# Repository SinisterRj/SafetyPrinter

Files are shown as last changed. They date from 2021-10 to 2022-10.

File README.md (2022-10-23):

# SafetyPrinter
This project aims to improve the safety of 3D FDM Printers by adding an external MCU (an Arduino) which increases your chance of preventing or mitigating a fire at your home.

Safety Printer MCU assembly
_Safety Printer MCU assembly_

The project itself is very simple and designed to be cheap (the minimum needed is an Arduino nano and a few sensors). All you need is some time to assemble everything and test.

This project has a sibling project, the [Octoprint's Safety Printer plugin](https://github.com/SinisterRj/Octoprint_SafetyPrinter) which is optional but it's highly recommended as it helps you monitor your sensors and helps a lot during test phase:

Sidebar1

You can find lots of information on [Wiki](https://github.com/SinisterRj/SafetyPrinter/wiki) and we recommend it's reading.

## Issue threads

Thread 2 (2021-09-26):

Request: List of supported sensors / smoke detectors

ascheucher, 2021-09-26:
Hi SinisterRJ,

just stumbled over your plugin / Arduino firmware. The idea sounds great!

I consider to build rebuild the whole thing in some time, but hove no idea which sensors / smoke detectors are supported.

Would you mind to list them in the Wiki?

Thanks in advance,
Andreas

SinisterRj, 2021-09-26:
Hi Andreas,

Nice sugestion, I'll implement. But you can use any smoke detector with "dry contact" alarm indication (usually they have four wire connection, two for power supply and 2 for the signal). They are the simpler ones. We don't offer support to any wireless sensor or 2 wire sensor that use any digital communication protocol.

ascheucher, 2021-09-27:
Thanks for your response. Had no experience with other than battery operated ones so far.
[Would this one for example be ok?](https://www.alibaba.com/product-detail/4-Wire-Relay-Output-Dry-Contact_60517976368.html)
It states dry contact...

[Is it wired up similar to this?](https://www.instructables.com/Prevent-House-Fires-with-the-Smoke-Detector-Discon/)

I assume your project is in early stage and there is more info (like wiring diagrams) to come?

SinisterRj, 2021-09-27:
Yes, this one is ok! And you don't need this kind of modification. A 4 wire smoke detector is very simple. 2 wires are the power supply, usually + 12 Vdc and Ground. The other 2 wires works like a ordinary switch. If you set it to be "normally open", the switch will de closed (short circuited) in normal condition, and will de open when some smoke hits the detector. Normally close is the oposite. Usually the detector have a jumper to select if you want a "normally open" or "normally close" mode.
All that you need to do about the wiring is to connect the 4 wires of the smoke sensor as drawed here:
[Schematics](https://github.com/SinisterRj/SafetyPrinter/blob/main/Schematics/Schematics.pdf)

ascheucher, 2021-09-28:
Oh, I missed the diagram!

Sounds good. Thanks for your explanation!

I hope I find time to dig into it soon.

SinisterRj, 2021-10-19:
Done!
[https://github.com/SinisterRj/SafetyPrinter/wiki/Supported-sensors](https://github.com/SinisterRj/SafetyPrinter/wiki/Supported-sensors)

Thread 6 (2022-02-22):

Feature Request: Support PSU Shutdown as subplugin

ivebeenlinuxed, 2022-02-22:
Would it be possible to implement a command in this library to query the printerPowered boolean as a new command "r6"?

This would give full functionality to implement the OctoPrint companion plugin as a subplugin of "PSUControl".

Sample source for subplugin requires "turn on", "turn off" and "get state":
https://github.com/kantlivelong/OctoPrint-PSUControl/blob/master/extra/psucontrol_subpluginexample.py

SinisterRj, 2022-02-23:
Hello!
I'm not sure if I got what you want. If do you mean to shutdown the printer when some sensor triggers throught another plugin, it is technically possible, but filosophically  speaking wrong. The idea behind this project is to have an automonous and independent system to shutdown your printer when everything else fails. So, the Safety Printer mcu (the arduino) takes this decision alone, the octoprint plugin is not needed for the safety action take its place. When you use another plugin to do that, many other parts must work flawlessly to the shutdown happens (i.e. rapsberry pi, octoprint, etc).

ivebeenlinuxed, 2022-02-24:
Hi! Thanks for the reply!

I completely agree that the safety printer plugin should autonomously, and without interferance, be able to shut down the printer. That is without question. I also agree that a safety interlock with another plugin is also a flawed implementation.

My point regards command <c6>. This allow the unit to "turn off/on" without the safety interlock state changing - from my brief understanding of the code. This is not a safety feature, but gives the user the choice of remotely turning off the unit when it is idle. I would assume the Octoprint option of "shutdown after print" uses this to cut power without tripping the interlock. Likewise, if the unit is tripped it will not start up again without a reset.

The "shutdown after print" is an overlapping feature with another plugin PSUControl. This power related (not safety related) feature would be better integrated into this plugin to improve support for "scheduled on/scheduled off/shutdown when cool/shutdown when idle" type features that SafetyPrinter implements to a lesser extent. This would prevent users having to attach a second device for powering the printer down at times of low demand.

My request would be simply that a new command would return 0 or 1, showing if the unit was powered off by <c6>. This would allow the PSUControl plugin to determine the current state of the relay and decide to power on and off the unit in innovative ways - supposing the interlock was not triggered. The PSU control could then issue a <c6> command to change the PSU state, should it want to.

This is not a safety feature, but offloading the user options of shutdowns and power ups, so long as the printer is safe, to another plugin. It does not give the plugin access to <reset>, which is completely different. What do you think?

SinisterRj, 2022-03-11:
Implemented via <r7> command. It returns "t" of "f" to printer's power on status.

Closed 2022-07-18.

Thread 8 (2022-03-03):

Bug: Octoprint_safetyprinter requires reset which cuts power on connect

ivebeenlinuxed, 2022-03-03:
At the moment, the octoprint plugin looks for the boot message when starting. This means that if the serial port to the safetyprinter disconnects, and then is made to reconnect the power is pulled to the printer during boot.

What would I like:
r7 command "ping" with a response "pong" to show that the Arduino is ready without having to reboot

ivebeenlinuxed, 2022-03-03:
I have a pull request for this, but not sure opening a pull request for r7 command, when r6 is still pending is wise

SinisterRj, 2022-03-03:
Hello my friend, this is an Arduino behavior not a safety printer's bug. Everytime you connect to an arduino (Uno ou nano) it resets. You can modify you arduino board to remove this feature, but you compromise other stuff (like need to reset upon a flash). Arduino Leonardo don't reset upon connection, but needs a manual reset to flash. This is something that I am working on.

ivebeenlinuxed, 2022-03-03:
Hi!

Indeed this is an Arduino feature, which I have solved with the 10uF capacitor between GND and RST. The issue is now that the printer needs to see another message apart from the boot message to know the connection is alive. I have replaced the connect test function to look for "pong" in response to "ping". This way, the board does not need to reboot to get the expected response message.

I shall send you the related pull request for the Octoprint plugin tomorrow.

SinisterRj, 2022-03-04:
I already fixed this at home but not pushed to GitHub yet, because I'm not sure if it is the best approach. I'm using [Firmware Updater Plugin](https://plugins.octoprint.org/plugins/firmwareupdater/) and  using the capacitor (or Arduino Leonardo) requires to push reset button to flash the firmware. Considering that the Safety Printer board will be usually located somewhere not very accessible and far from the computer, it will be impractical to use the plugin to update the safety printer`s firmware.

SinisterRj, 2022-03-04:
Maybe, one approach is to use the raspberry pi to force arduino`s reset or, create some command to reset the Arduino.

SinisterRj, 2022-03-11:
Hello. I updated the github with my latest code (devel branch). It already supports Arduino Leonardo (or Uno/nano with the capacitor to avoid reset), but you must reflash your arduino with the devel firmware too.

ivebeenlinuxed, 2022-03-28:
Hi @SinisterRj - Sorry for the delay. I've been away and didn't have access to my printer.

The other problem that needs fixing is that the Octoprint_SafetyPrinter needs to not wait for the boot text, but if already booted, should wait for a "ping".

I've put this here:
https://github.com/ivebeenlinuxed/Octoprint_SafetyPrinter/commit/507307af4ccb8985f92de0c35f0469ff2cc52220

The corresponding "ping" command is in my commit here:
https://github.com/ivebeenlinuxed/SafetyPrinter/commit/856076953db4fa97ddb625f6897dfc941f4eed87

Obviously there are some backwards compatibility issues here, as older versions of the SafetyPrinter firmware does not have the new "ping" command.

I guess this will need some tweaking, and maybe I need to get this all committed on dev branches....

Shall I do two pull requests for these - one to each repo?

SinisterRj, 2022-07-19:
Hello @ivebeenlinuxed . I've been away from the project for some time, and now I could take a look on your suggestions. The problem avoiding the reset with a capacitor creates another problem: the need of pressing the reset button to flash the arduino. I studied the problem for some time, because I did want to solve it by software, but as far I went, the bootloader just enters in programming mode when the RST pin is lowered. So I couldn't find another way than use a digital port to autoreset the arduino.
After this been said, I was already understod that the handshake should be different and already changed it locally, So I will use my code.
And thanks for the "threading" commit.
I hope you enjoy the new devel release, but keep in mind that you will need to reflash your arduino.

Closed 2022-07-19.

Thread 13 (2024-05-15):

WatchDog library only supports AVR processors

ctbjdm, 2024-05-15:
There aren't any clear specs for the Arduino beyond "Arduino Uno or Nano".  Trying to compile it in the Arduino IDE, for an Arduino UNO R4 Minima (seemed like a reasonable purchase for this) doesn't work.  I get the error below.

Seems you need to use an AVR core based Arduino to use this as-is.  Switching to an older AVR Arduino (ordered) to see if it resolves it.

------------------------------------------------------------------------------------------------------------
In file included from C:\Users\me\Documents\Arduino\SafetyPrinter\SafetyPrinter.ino:1:0:
C:\Users\me\Documents\Arduino\libraries\WatchDog/WatchDog.h:78:2: error: #error The WatchDog library only supports AVR processors
 #error The WatchDog library only supports AVR processors
  ^~~~~
C:\Users\me\Documents\Arduino\SafetyPrinter\SafetyPrinter.ino:112:10: fatal error: avr/wdt.h: No such file or directory
 #include <avr/wdt.h>                        // Watchdog
          ^~~~~~~~~~~
compilation terminated.
exit status 1

Compilation error: avr/wdt.h: No such file or directory
------------------------------------------------------------------------------------------------------------

Note - this looks excellent - thank you SinisterRj

SinisterRj, 2024-07-26:
BOM updated with the right MCU information. Thanks

Closed 2024-07-26.

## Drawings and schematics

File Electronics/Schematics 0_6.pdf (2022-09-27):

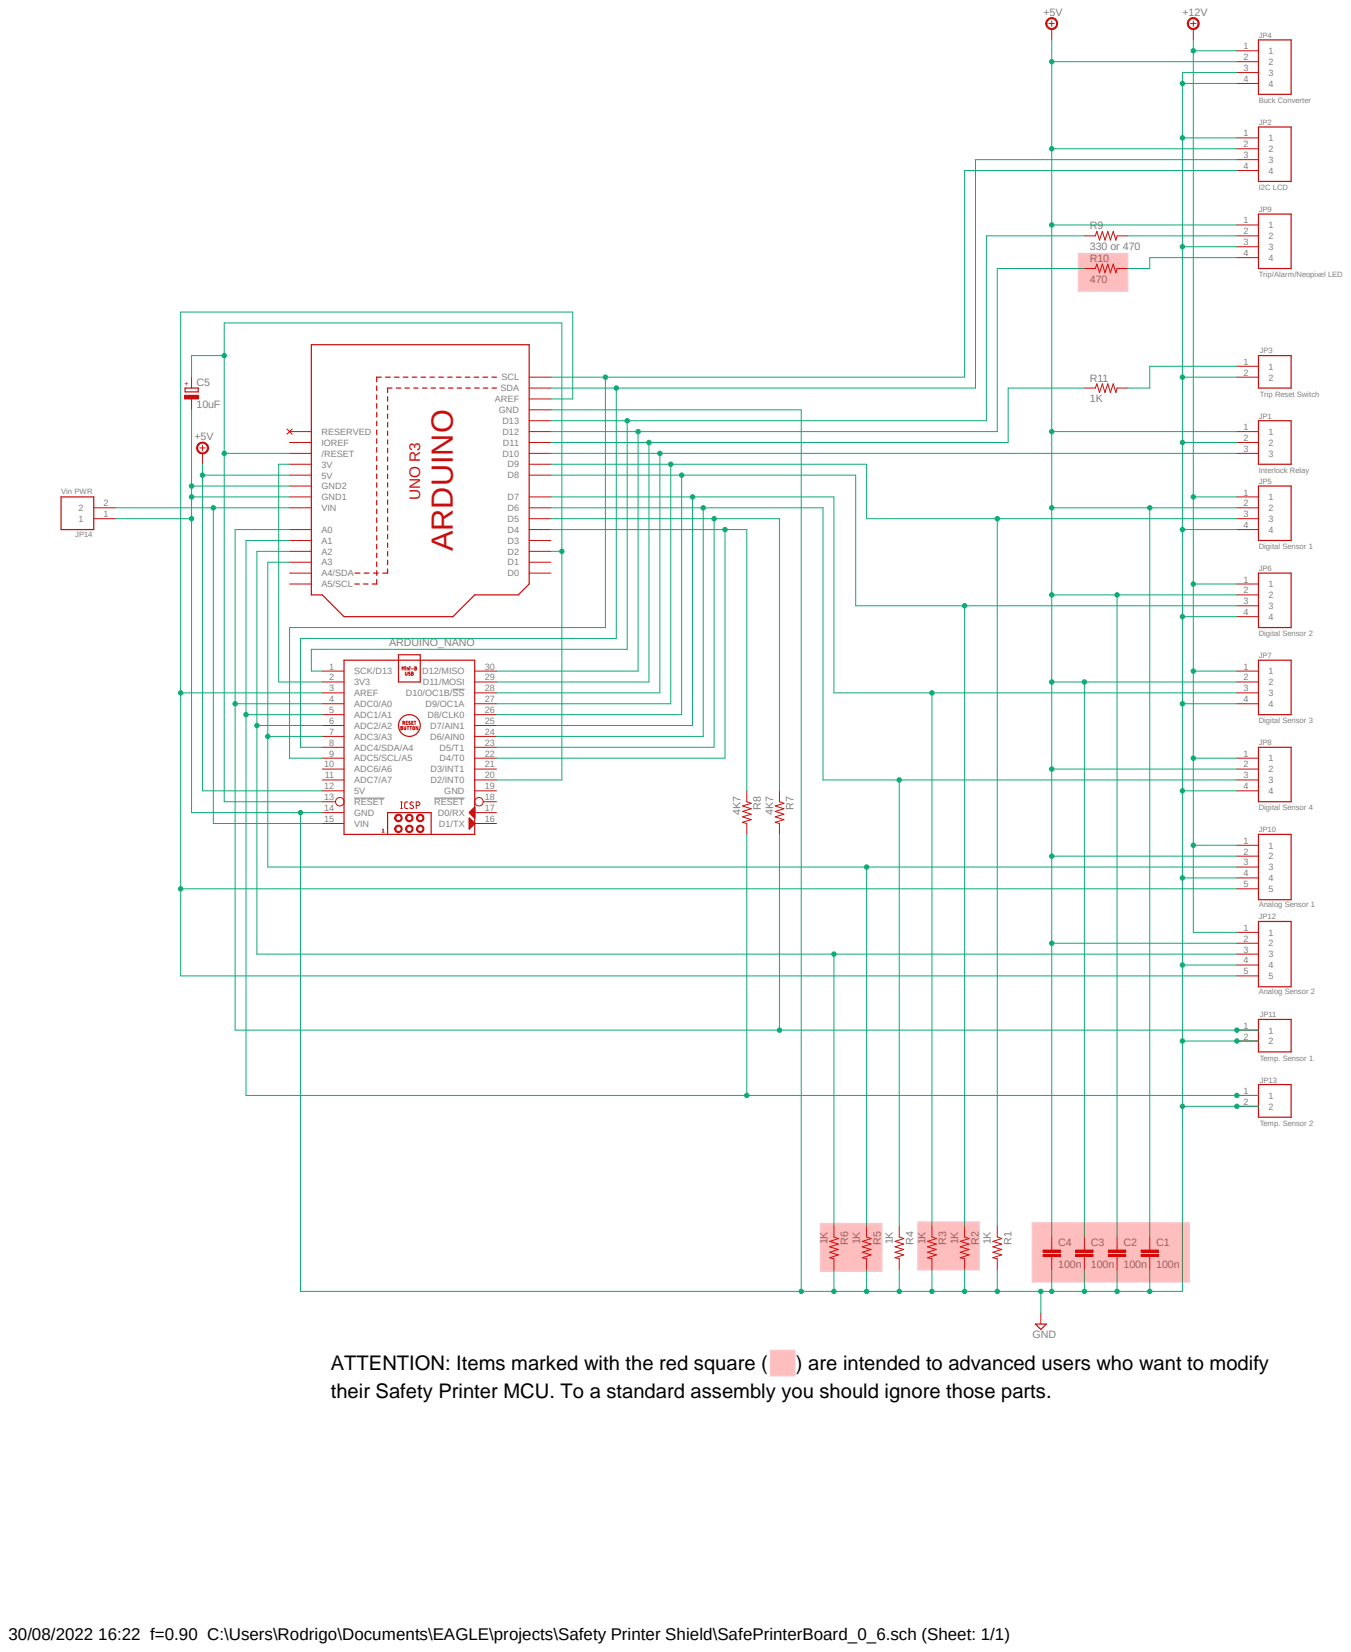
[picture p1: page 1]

JP9 Trip/Alarm/Neopixel LED ARDUINO UNO R³

30/08/2022 16:22 f=0.90 C:\Users\Rodrigo\Documents\EAGLE\projects\Safety Printer Shield\SafePrinterBoard_0_6.sch (Sheet: 1/1)

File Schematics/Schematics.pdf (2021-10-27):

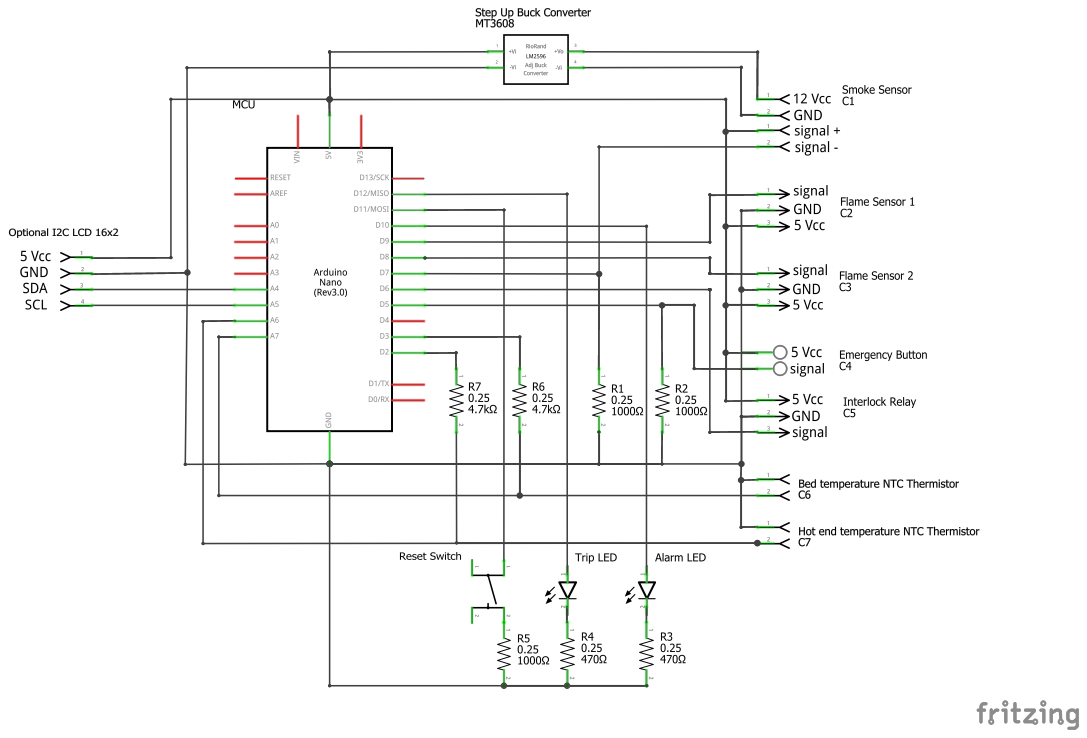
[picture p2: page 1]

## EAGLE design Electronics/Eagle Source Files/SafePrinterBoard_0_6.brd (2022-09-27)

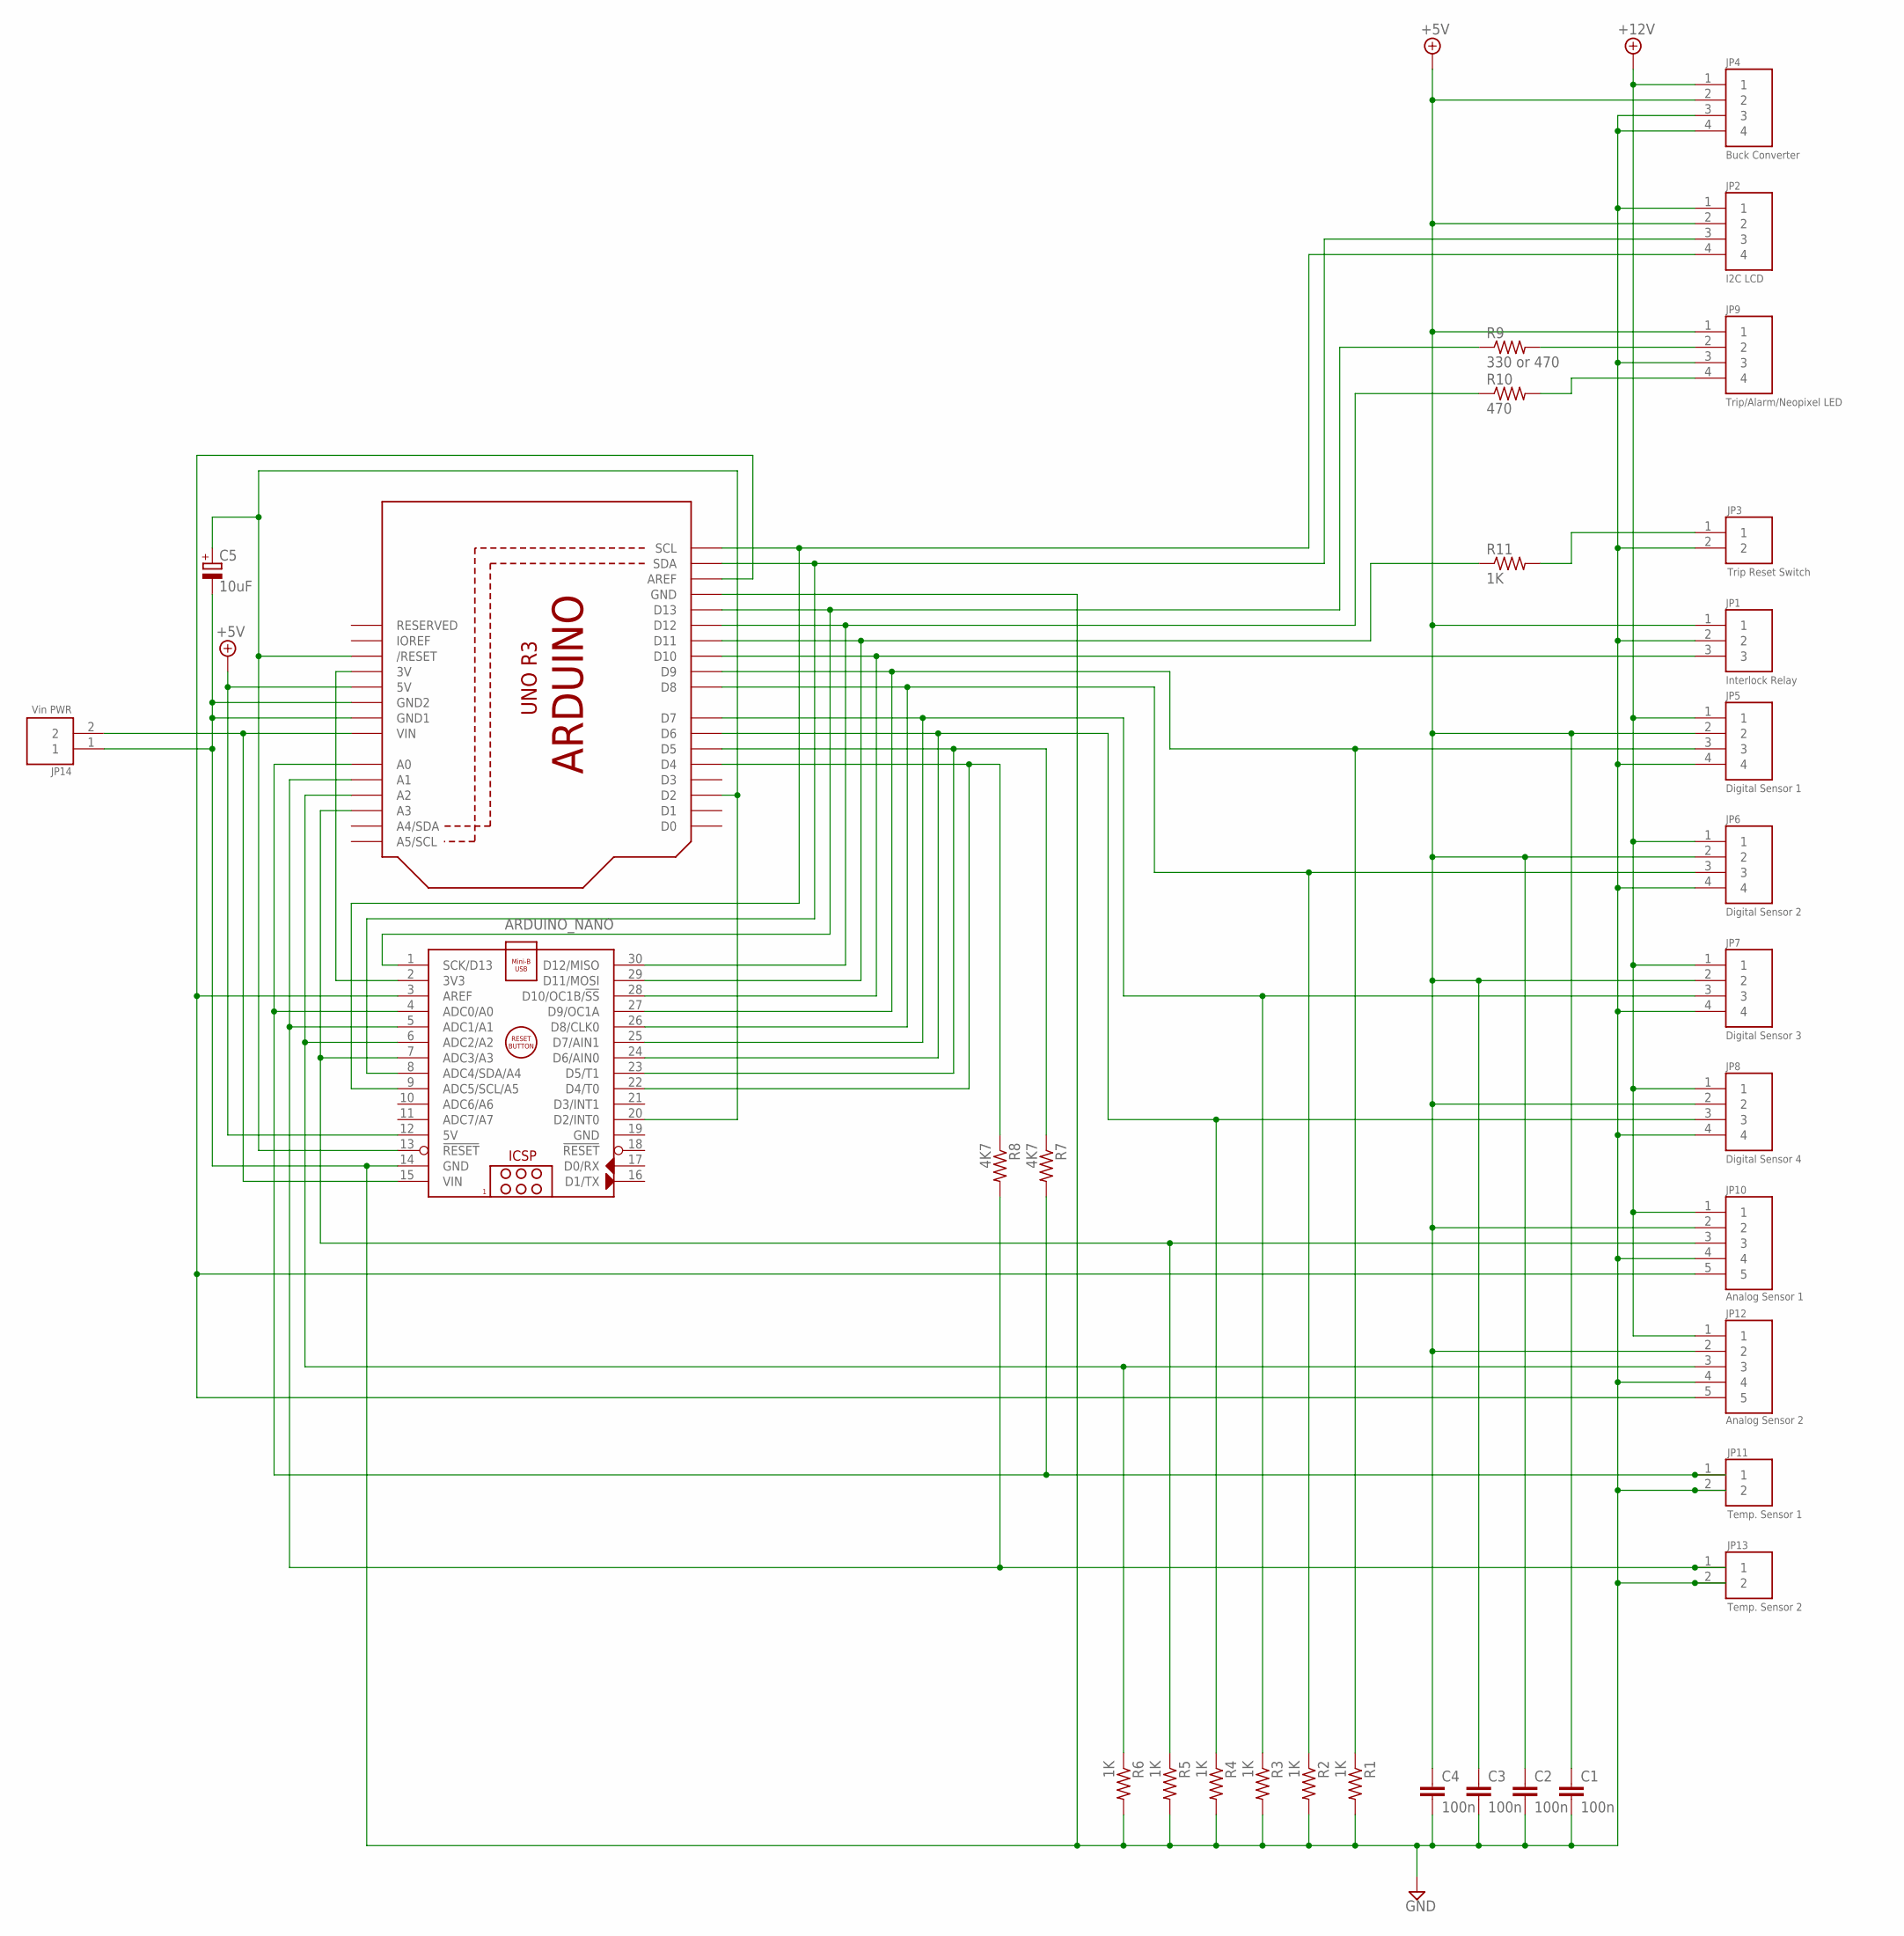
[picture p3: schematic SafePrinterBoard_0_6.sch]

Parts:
ARDUINO_NANO: ARDUINO_NANO
C1, C2, C3, C4: 100n; C025-025X050
C5: 10uF; E2-5
JP1: Interlock Relay; B3B-PH-K-S
JP2: I2C LCD; B4B-PH-K-S
JP3: Trip Reset Switch; B2B-PH-K-S
JP4: Buck Converter; B4B-PH-K-S
JP5: Digital Sensor 1; B4B-PH-K-S
JP6: Digital Sensor 2; B4B-PH-K-S
JP7: Digital Sensor 3; B4B-PH-K-S
JP8: Digital Sensor 4; B4B-PH-K-S
JP9: Trip/Alarm/Neopixel LED; B4B-PH-K-S
JP10: Analog Sensor 1; B5B-PH-K-S
JP11: Temp. Sensor 1; B2B-PH-K-S
JP12: Analog Sensor 2; B5B-PH-K-S
JP13: Temp. Sensor 2; B2B-PH-K-S
JP14: Vin PWR; B2B-PH-K-S
R1, R2, R3, R4, R5, R6, R11: 1K; 0805-THM
R7, R8: 4K7; 0805-THM
R9: 330 or 470; 0805-THM
R10: 470; 0805-THM
U1: ARDUINOR3-BPLACE

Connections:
+5V: ARDUINO_NANO.12 (5V), C1.1, C2.1, C3.1, C4.1, JP1.1, JP2.2, JP4.2, JP5.2, JP6.2, JP7.2, JP8.2, JP9.1, JP10.2, JP12.2, U1.5V
+12V: JP4.1, JP5.1, JP6.1, JP7.1, JP8.1, JP10.1, JP12.1
GND4: ARDUINO_NANO.14 (GND), ARDUINO_NANO.19 (GND), C1.2, C2.2, C3.2, C4.2, C5.-, JP1.2, JP2.1, JP3.2, JP4.3, JP4.4, JP5.4, JP6.4, JP7.4, JP8.4, JP9.3, JP10.4, JP11.2, JP12.4, JP13.2, JP14.1, R1.2, R2.2, R3.2, R4.2, R5.2, R6.2, U1.GND, U1.GND1, U1.GND2
unnamed: ARDUINO_NANO.28 (D10/OC1B/!SS), JP1.3, U1.D10
unnamed: ARDUINO_NANO.24 (D6/AIN0), JP8.3, R4.1, U1.D6
unnamed: JP9.2, R9.2
unnamed: ARDUINO_NANO.26 (D8/CLK0), JP6.3, R2.1, U1.D8
unnamed: ARDUINO_NANO.25 (D7/AIN1), JP7.3, R3.1, U1.D7
unnamed: ARDUINO_NANO.27 (D9/OC1A), JP5.3, R1.1, U1.D9
unnamed: ARDUINO_NANO.1 (SCK/D13), R9.1, U1.D13
unnamed: ARDUINO_NANO.30 (D12/MISO), R10.1, U1.D12
unnamed: ARDUINO_NANO.29 (D11/MOSI), R11.1, U1.D11
unnamed: ARDUINO_NANO.9 (ADC5/SCL/A5), JP2.4, U1.SCL
unnamed: ARDUINO_NANO.8 (ADC4/SDA/A4), JP2.3, U1.SDA
unnamed: ARDUINO_NANO.23 (D5/T1), R7.1, U1.D5
unnamed: JP9.4, R10.2
unnamed: ARDUINO_NANO.22 (D4/T0), R8.1, U1.D4
unnamed: ARDUINO_NANO.7 (ADC3/A3), JP10.3, R5.1, U1.A3
unnamed: ARDUINO_NANO.6 (ADC2/A2), JP12.3, R6.1, U1.A2
unnamed: ARDUINO_NANO.13 (!RESET), ARDUINO_NANO.20 (D2/INT0), C5.+, U1.D2, U1.RESET (/RESET)
unnamed: ARDUINO_NANO.15 (VIN), JP14.2, U1.VIN
unnamed: ARDUINO_NANO.4 (ADC0/A0), JP11.1, R7.2, U1.A0
unnamed: ARDUINO_NANO.5 (ADC1/A1), JP13.1, R8.2, U1.A1
unnamed: ARDUINO_NANO.3 (AREF), JP10.5, JP12.5, U1.AREF
unnamed: ARDUINO_NANO.2 (3V3), U1.3V
unnamed: JP3.1, R11.2

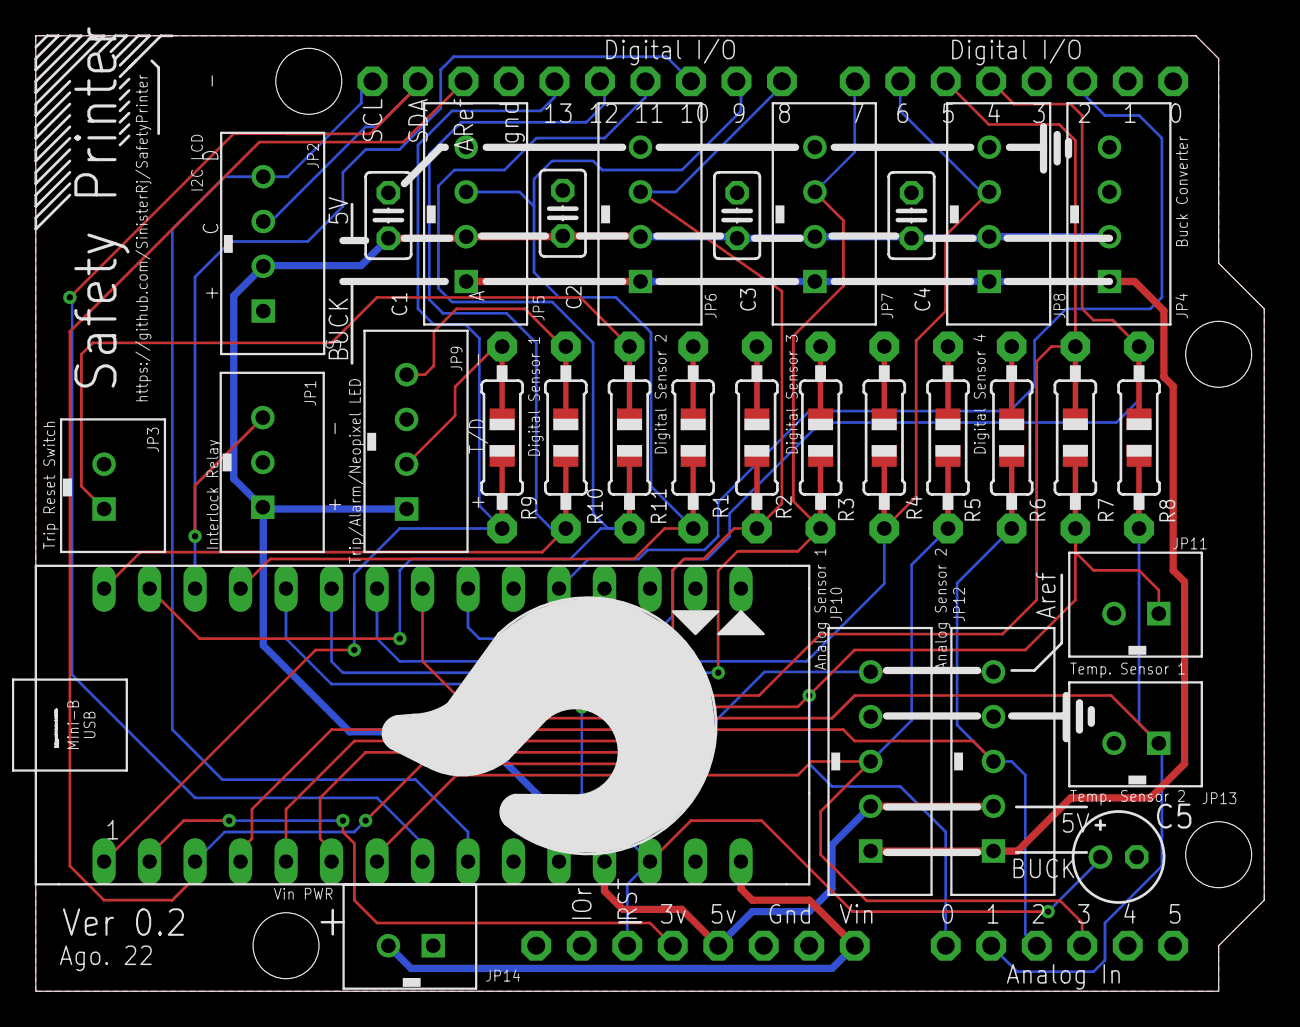
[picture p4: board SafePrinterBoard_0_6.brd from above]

Board: 2 copper layers, 68.6 x 53.3 mm, 32 parts (0 on the bottom side), 26 nets.

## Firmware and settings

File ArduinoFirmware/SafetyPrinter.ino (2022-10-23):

/**
 * Safety Printer Firmware
 * Copyright (c) 2021~22 Rodrigo C. C. Silva [https://github.com/SinisterRj/SafetyPrinter]
 *
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
 * WARNING: DON'T CHANGE ANYTHING IN THIS FILE! ALL CONFIGURATIONS SHOULD BE DONE IN "Configurations.h".
 *
 * Version 0.2.7
 * 22/10/22
 * Changes:
 * 1) Monitors RESET button to a continuous operation (shortcircuited) and disables it to avoid auto reset after a trip.
 * 2) Fix a bug that crashes the serial communication if the sensor Label was grater then 16 chars.
 * 
 * Version 0.2.6
 * 27/09/22
 * Changes:
 * 1) New default pin out to match with the official Safety Printer Arduino Shield;
 * 2) Include <R6> command to repeat intro msg;
 * 3) Remove "booting..." string from the setup;
 * 4) Auto detects different Arduino boards;
 * 5) Include command <r7> to report Printer's power status (user request) - Integration with PSU Control;
 * 6) Include command <c9> to reset the Safety Printer MCU. This command allows firmware update.
 * 7) Command <R4> returns board Type;
 * 8) Include ARDUINO_RESET_PIN;
 * 9) Include neopixels as status indicator;
 * 10) Fix a bug that makes wrong temperature readings if your declared sensor that don't match with the sensor's count.
 * 
 * Version 0.2.5
 * 10/21/2021
 * Changes:
 * 1) Include CRC check on <r1>,<r2> and <r4> responses;
 * 2) Organize some thermisotr tables and Configuration.h file;
 * 3) Check for some errors on sensor configuration and disable it.
 * 4) Include commands alias;
 * 5) Include free memory, voltage, temperature and cycle time monitoring;
 * 6) Include I2C 16x2 LCD support
 * 7) Creates "lowSP" and "highSP" sensor values (now user can choose different sensors);
 * 8) <R2> now sends "forceEnable", "lowSP" and "highSP" values;
 * 9) Include a timer to avoid sucessive trips/resets or turns on/off on printer and damage it.
 * 
 * Version 0.2.4
 * 07/30/2021
 * Changes:
 * 1) Include Marlin Thermistor files for better thermistor configuration;
 * 2) Configuration.h created.
 *
 * Version 0.2.3
 * Changes:
 * 1) Fix a bug when reading EEPROM data.
 * 2) Split project into multiple files.
 * 3) Checks EEPROM for CRC.
 * 4) Update <c4> command to send EEPROM and Serial Protocol versions
 * 
 * Version 0.2.2
 * Changes:
 * 1) Defined limits for set point definition.
 * 2) Now EEPROM read uses the addr 0 as a version flag. If it is different from EEPROMVERSION (because new release changed EEPROM structure), the firmware will overwrite it.
 * 3) Include command C5 to turn off the printer.
 * 4) Commands and arguments are now case insensitive.
 * 5) Included command <c7> to change sensor timers.
 * 6) included command <c1> to return sensors configuration (enabled, alarm set point and timer) back to original values.
 * 7) Fix a bug that interpretates no argument as argument 0 in some commands.
 * 
 * Version: 0.2.1
 * 05/26/2021
 * Changes: 
 * 1) Include analog type of sensor to allow Hotend temperature measurement.
 * 2) included command <c5> to save on EEPROM sensors Enabled status and alarm set points
 * 3) 2 new serial commands: Remote shutdown and enable/disable sensors 
 * 4) Now it indicates Alarm even if the sensor is disabled (but not starts de trip)
 * 5) Included command <r4> to return firmware version and release date
 * 
 */
 
//#define DEBUG   
#ifdef DEBUG                                // Just for debug porpouses
  #define DEBUG_DELAY           1000        // Debug timer renew
#endif

#define LOOP_TIME_SAMPLES       25          // Number of samples to calculate main loop time.

#define DIGIGTAL_SENSOR         0           // Internal use, don't change
#define NTC_SENSOR              1           // Internal use, don't change

// Board Codes
#define UNO                     1
#define NANO                    2
#define LEONARDO                3

//Number of chars in sensors label
#define NUMCHARLABEL            16

#include <Arduino.h>                        // Needed to compile with Platformio
#include <avr/wdt.h>                        // Watchdog
#include <EEPROM.h>                         // EEPROM access
#include "Configuration.h"

#ifdef HAS_LCD
  #include <Wire.h>
  #include <LiquidCrystal_I2C.h>
#endif

// *************************** Don't change after this line **********************************
// *******************************************************************************************

#define VERSION                 "0.2.7"
#define RELEASEDATE             "Oct 13 2022"
#define EEPROMVERSION           3            // Incremental BYTE. Firmware overwrites the EEPROM with standard values if the number readed from EEPROM is different. change everytime that EEPROM structure is changed.
#define COMMPROTOCOL            6            // Incremental BYTE. Octoprint plugin communication protocol version. 

char forb_chars[] = {',','#','$',':','<','>'};   // forbiden characters for sensor names
//int availableThermistors[] = {1,2,3,4,5,6,7,8,9,10,11,12,13,15,17,18,20,21,22,23,30,51,52,55,60,61,66,67,70,71,75,99,331,332,998,999};
 
// another .ino functions:
int highest_temp(byte sensorNumber);
int lowest_temp(byte sensorNumber);

typedef struct
{
  int8_t index;
  char label[NUMCHARLABEL+1];
  int8_t pin;
  int8_t auxPin;
  uint8_t type;
  unsigned long timer;
  int alarmSP;
  bool enabled;
  bool active;
  int actualValue;
  bool forceDisable;
  bool trigger;
  int lowSP;
  int highSP;
  int16_t tTI; //temp table index
} tSensor;

typedef struct
{
  unsigned long timer;
  int alarmSP;
  bool enabled;
} tDefault;

/* ****************************************************************************
 Declare all sensors using the above template
 "label",pin number,delay,enabled,alarmStatus,forceDisable,trigger,spare3,spare4

 Label: the name of the sensor, that will help you to intentify it;
 Pin number: the pin wher it is connected;
 Delay: The timer delay to start the interlock from this sensor. If two or more sensors are active, the delay is bypassed; 
 Normal Condition: The variable status during normal operation. For analog variables, use the greater normal value (i.e. 279 if you want to trip with 280)
 enabled, alarmStatus: Internal use.

*/

tSensor sensors [] =
{   
#ifdef SENSOR_1_LABEL
   0,"",SENSOR_1_PIN,
   #ifdef SENSOR_1_AUX_PIN 
      SENSOR_1_AUX_PIN, 
   #else 
      -1, 
   #endif
   SENSOR_1_TYPE,SENSOR_1_TIMER,SENSOR_1_ALARM_SP,true,false,0,false,false,
   #ifdef SENSOR_1_TEMP_TYPE 
      0,0,SENSOR_1_TEMP_TYPE, 
   #else 
      0,1,0,
   #endif
#endif 
#ifdef SENSOR_2_LABEL
   1,"",SENSOR_2_PIN,
   #ifdef SENSOR_2_AUX_PIN 
      SENSOR_2_AUX_PIN, 
   #else 
      -1, 
   #endif
   SENSOR_2_TYPE,SENSOR_2_TIMER,SENSOR_2_ALARM_SP,true,false,0,false,false,
   #ifdef SENSOR_2_TEMP_TYPE 
      0,0,SENSOR_2_TEMP_TYPE, 
   #else 
      0,1,0,
   #endif
#endif 
#ifdef SENSOR_3_LABEL
   2,"",SENSOR_3_PIN,
   #ifdef SENSOR_3_AUX_PIN 
      SENSOR_3_AUX_PIN, 
   #else 
      -1, 
   #endif
   SENSOR_3_TYPE,SENSOR_3_TIMER,SENSOR_3_ALARM_SP,true,false,0,false,false,
   #ifdef SENSOR_3_TEMP_TYPE 
      0,0,SENSOR_3_TEMP_TYPE, 
   #else 
      0,1,0, 
   #endif
#endif 
#ifdef SENSOR_4_LABEL
   3,"",SENSOR_4_PIN,
   #ifdef SENSOR_4_AUX_PIN 
      SENSOR_4_AUX_PIN, 
   #else 
      -1, 
   #endif
   SENSOR_4_TYPE,SENSOR_4_TIMER,SENSOR_4_ALARM_SP,true,false,0,false,false,
   #ifdef SENSOR_4_TEMP_TYPE 
      0,0,SENSOR_4_TEMP_TYPE, 
   #else 
      0,1,0, 
   #endif
#endif 
#ifdef SENSOR_5_LABEL
   4,"",SENSOR_5_PIN,
   #ifdef SENSOR_5_AUX_PIN 
      SENSOR_5_AUX_PIN, 
   #else 
      -1, 
   #endif
   SENSOR_5_TYPE,SENSOR_5_TIMER,SENSOR_5_ALARM_SP,true,false,0,false,false,
   #ifdef SENSOR_5_TEMP_TYPE 
      0,0,SENSOR_5_TEMP_TYPE, 
   #else 
      0,1,0, 
   #endif
#endif 
#ifdef SENSOR_6_LABEL
   5,"",SENSOR_6_PIN,
   #ifdef SENSOR_6_AUX_PIN 
      SENSOR_6_AUX_PIN, 
   #else 
      -1, 
   #endif
   SENSOR_6_TYPE,SENSOR_6_TIMER,SENSOR_6_ALARM_SP,true,false,0,false,false,
   #ifdef SENSOR_6_TEMP_TYPE 
      0,0,SENSOR_6_TEMP_TYPE, 
   #else 
      0,0,0, 
   #endif
#endif 
#ifdef SENSOR_7_LABEL
   6,"",SENSOR_7_PIN,
   #ifdef SENSOR_7_AUX_PIN 
      SENSOR_7_AUX_PIN, 
   #else 
      -1, 
   #endif
   SENSOR_7_TYPE,SENSOR_7_TIMER,SENSOR_7_ALARM_SP,true,false,0,false,false,
   #ifdef SENSOR_7_TEMP_TYPE 
      0,0,SENSOR_7_TEMP_TYPE, 
   #else 
      0,1,0, 
   #endif
#endif 
#ifdef SENSOR_8_LABEL
   7,"",SENSOR_8_PIN,
   #ifdef SENSOR_8_AUX_PIN 
      SENSOR_8_AUX_PIN, 
   #else 
      -1, 
   #endif
   SENSOR_8_TYPE,SENSOR_8_TIMER,SENSOR_8_ALARM_SP,true,false,0,false,false,
   #ifdef SENSOR_8_TEMP_TYPE 
      0,0,SENSOR_8_TEMP_TYPE, 
   #else 
      0,1,0, 
   #endif
#endif 
};

tDefault defaultSensors[(sizeof(sensors) / sizeof(sensors[0]))];

typedef struct
{
  unsigned long startMs = 0;
  bool started = false;
} tTimer;

/*
//Defines the SP limits for each of the sensor types. 
int SPLimits[2][2] = {
  { 0, 1 },   // type 0 = Digital
  { 0, 300 }  // type 1 = NTC temperature
};*/
bool interlockStatus = false;
bool interlockStatusChanged = false;
bool anyAlarm = false;
uint8_t activeAlarmCount = 0;
uint8_t numOfSensors = 0;
tTimer interlockTimer, resetTimer, minimumInterlockTimer, inhibitResetTimer;
bool printerPowered = true;
unsigned int lTLastRecord = 0;
long lTStartTime;
long lTSum = 0;
long lTMax = 0;
long lTNow, lTLastMax, lTLastSum;
bool memWrng, tempWrng, voltWrng, execWrng  = false;
byte triggerIndex = 255;
bool resetBtnPressed = false;
bool inhibitReset = false;



#ifdef DEBUG
   tTimer debugTimer;
#endif

#ifdef HAS_LCD
  tTimer LCDTimer;
  bool tripLCD = false;
#endif

#ifdef HAS_SERIAL_COMM
  #define SERIAL Serial
#endif

void setup() {

   //Enabling watchdog timer 4s  
   wdt_enable(WDTO_4S);

   pinMode(ARDUINO_RESET_PIN, OUTPUT);
   digitalWrite(ARDUINO_RESET_PIN, HIGH);
   
   #ifdef HAS_SERIAL_COMM
      SERIAL.begin(BAUD_RATE);
   #endif

   #ifdef HAS_LCD
      lcd_Init();
   #endif
   
   #ifdef HAS_NEOPIXEL ||  ALARM_LED_PIN || TRIP_LED_PIN  
      led_Init();
   #endif
  
   #ifdef RESET_BUTTON_PIN
      pinMode(RESET_BUTTON_PIN, INPUT_PULLUP);
   #endif

   pinMode(INTERLOCK_RELAY_PIN, OUTPUT);
   digitalWrite(INTERLOCK_RELAY_PIN, INTERLOCK_POLARITY);
   startTimer(&minimumInterlockTimer.startMs,&minimumInterlockTimer.started);

   numOfSensors = (sizeof(sensors) / sizeof(sensors[0]));
  
   // check sensor configuration
   validateSensorsInfo();
   
   //Set sensor input pins
   for (int i =0; i < numOfSensors; i++) { 
      if (sensors[i].enabled && !sensors[i].forceDisable) 
      {
         pinMode(sensors[i].pin, INPUT);
         if (sensors[i].auxPin != -1) {
            pinMode(sensors[i].auxPin, OUTPUT);  // Configure power pin. This pin will be used to power the thermistor
         }
      }          
   }

   for (int i =0; i < numOfSensors; i++) { 
      defaultSensors[i].timer = sensors[i].timer;
      defaultSensors[i].alarmSP = sensors[i].alarmSP;
      if (!sensors[i].forceDisable) {
         defaultSensors[i].enabled = sensors[i].enabled;
      } else {
         defaultSensors[i].enabled = false;
      }
   }

   readEEPROMData(); 

   #ifdef DEBUG
      startTimer(&debugTimer.startMs,&debugTimer.started);
   #endif

   #ifdef HAS_LCD
      startTimer(&LCDTimer.startMs,&LCDTimer.started);
   #endif
}

void loop() {

   // Save the loop start time
   lTStartTime = micros();
 
   //Verify sensors
   checkSensors();

   //Verify reset button
   #ifdef RESET_BUTTON_PIN
      checkResetButton();
   #endif

   //Update LEDs
   updateLEDs();   
  
   //Manage Serial communications
   #ifdef HAS_SERIAL_COMM
      // Receive commands from PC
      recvCommandWithStartEndMarkers(); 
   #endif

   //update LCD information 
   #ifdef HAS_LCD
      updateLCD(resetBtnPressed);
   #endif   

   //Debug Info
   #ifdef DEBUG
      if (checkTimer(&debugTimer.startMs,DEBUG_DELAY,&debugTimer.started)) { 
         SERIAL.println();
         SERIAL.print (F("Free memory [bytes]= "));  // 2048 bytes from datasheet
         SERIAL.println (freeMemory());
         SERIAL.print (F("Temperature [C]= "));
         SERIAL.println (readTemp(), 2);
         SERIAL.print (F("Voltage [V]= "));
         SERIAL.println (readVcc(), 2);  // 2.7V to 5.5V from datasheet
         SERIAL.print (F("Execution time max [us] = "));
         SERIAL.println (lTLastMax,DEC); 
         SERIAL.print (F("Execution time average [us] = "));
         SERIAL.println (lTLastSum/LOOP_TIME_SAMPLES, DEC); 
      } else {
         startTimer(&debugTimer.startMs,&debugTimer.started);
      } 
   #endif

   // check board health:
   if (freeMemory() < 205) {  // 10% of total SRAM
      memWrng = true;
   }
   if ((readTemp() > 110) || (readTemp() < -25)) {  // -40 to +125 +-15
      tempWrng = true;
   }
   if ((readVcc() < 2.7) || (readVcc() > 5.5)) { // 2.7 to 5.5 Vcd 
       voltWrng = true;
   }

   // Measures the execution time
   lTLastRecord++;   
   lTNow = micros() - lTStartTime;   
   lTSum += lTNow;
   
   if (lTNow > lTMax) {
      lTMax = lTNow;    
   }
   
   if (lTLastRecord >= LOOP_TIME_SAMPLES) {
      lTLastSum = lTSum;
      lTSum = 0;
      lTLastMax = lTMax;
      lTMax = 0;      
      lTLastRecord = 0;
      if (lTLastMax > 500000) {   // 500 ms
         execWrng = true;
      }
   } 
   
   //Reset watchdog timer
   wdt_reset();
}

void validateSensorsInfo() {   
   // Check sensor configurations that cannot be done by pre-processor
   byte usedPins[21];
   byte arrayPos = 0;
   #ifdef INTERLOCK_RELAY_PIN
      usedPins[arrayPos] = INTERLOCK_RELAY_PIN;
      arrayPos++;
   #endif

   #ifdef RESET_BUTTON_PIN
      usedPins[arrayPos] = RESET_BUTTON_PIN;
      arrayPos++;
   #endif
    
   #ifdef ALARM_LED_PIN
      usedPins[arrayPos] = ALARM_LED_PIN;
      arrayPos++;
   #endif
    
   #ifdef TRIP_LED_PIN
      usedPins[arrayPos] = TRIP_LED_PIN;
      arrayPos++;
   #endif
    
   #ifdef LCD_SDA_PIN
      usedPins[arrayPos] = LCD_SDA_PIN;
      arrayPos++;
   #endif
    
   #ifdef LCD_SCL_PIN
      usedPins[arrayPos] = LCD_SCL_PIN;
      arrayPos++;
   #endif

   // Crops the sensor label if it is larger than NUMCHARLABEL
   #ifdef SENSOR_1_LABEL
   strncpy(sensors[0].label, SENSOR_1_LABEL, NUMCHARLABEL);
   #endif
   #ifdef SENSOR_2_LABEL
   strncpy(sensors[1].label, SENSOR_2_LABEL, NUMCHARLABEL);
   #endif
   #ifdef SENSOR_3_LABEL
   strncpy(sensors[2].label, SENSOR_3_LABEL, NUMCHARLABEL);
   #endif
   #ifdef SENSOR_4_LABEL
   strncpy(sensors[3].label, SENSOR_4_LABEL, NUMCHARLABEL);
   #endif
   #ifdef SENSOR_5_LABEL
   strncpy(sensors[4].label, SENSOR_5_LABEL, NUMCHARLABEL);
   #endif
   #ifdef SENSOR_6_LABEL
   strncpy(sensors[5].label, SENSOR_6_LABEL, NUMCHARLABEL);
   #endif
   #ifdef SENSOR_7_LABEL
   strncpy(sensors[6].label, SENSOR_7_LABEL, NUMCHARLABEL);
   #endif
   #ifdef SENSOR_8_LABEL
   strncpy(sensors[7].label, SENSOR_8_LABEL, NUMCHARLABEL);
   #endif
   
   for (byte i = 0; i < numOfSensors; i++) {
      //sensors[i].label = sensors[i].label.substring(0,16);
      for (byte j = 0; j < sizeof(sensors[i].label); j++) {
         for (byte x = 0; x < sizeof(forb_chars); x++) {
            //sensors[i].label.replace(forb_chars[j],'?');
            if (sensors[i].label[j] == forb_chars[x]) {
               sensors[i].label[j] = '?';
            }
         }
      }
      usedPins[arrayPos] = sensors[i].pin;
      arrayPos++;
      if (sensors[i].auxPin != -1) {
         usedPins[arrayPos] = sensors[i].auxPin;
         arrayPos++;
      }
      if (sensors[i].type == NTC_SENSOR) {
         sensors[i].highSP = highest_temp(sensors[i].index);
      }
      if (sensors[i].type == NTC_SENSOR) {
         sensors[i].lowSP = lowest_temp(sensors[i].index);
      }     
      if ((sensors[i].alarmSP < sensors[i].lowSP) || (sensors[i].alarmSP > sensors[i].highSP)) {
         #ifdef HAS_SERIAL_COMM
            SERIAL.print(sensors[i].label);
            SERIAL.print(F(": Wrong sensor ALARM SET POINT ("));
            SERIAL.print(sensors[i].alarmSP);
            SERIAL.print(F("). Range: "));
            SERIAL.print(sensors[i].lowSP);
            SERIAL.print(F(" to "));
            SERIAL.print(sensors[i].highSP);
            SERIAL.println(F(". Check your Configuration.h file. Sensor disabled."));
         #endif
         sensors[i].alarmSP = 0;
         sensors[i].enabled = false;
         sensors[i].forceDisable = true;
      }    
   }
   for (byte i = 0; i < arrayPos-1; i++) {
      for (byte j = i+1; j < arrayPos; j++) {
         if (usedPins[i] == usedPins[j] && usedPins[i] != -1){
            // Duplicated pin assignment found.
            for (byte x = 0; x < numOfSensors; x++){
               if (sensors[x].pin == usedPins[i] || sensors[x].auxPin == usedPins[i]) {
                  sensors[x].enabled = false;
                  sensors[x].forceDisable = true;
                  #ifdef HAS_SERIAL_COMM
                     SERIAL.print(sensors[x].label);
                     SERIAL.println(F(": Multiple assings to the same I/O pin. Check your Configuration.h file. Sensor disabled."));
                  #endif
               }
            }
         }
      }
   }
}

void checkSensors() {
   // Check all inputs for new alamrs
   activeAlarmCount = 0;
   anyAlarm = false;
   for (byte i =0; i < numOfSensors; i++) { 
      if (sensors[i].type == DIGIGTAL_SENSOR){
        sensors[i].actualValue = digitalRead(sensors[i].pin);
        if (sensors[i].actualValue == sensors[i].alarmSP) {
           setAlarm(i);
        } else {
           sensors[i].active = false;
        }
      }
      else if (sensors[i].type == NTC_SENSOR) {
        sensors[i].actualValue = read_temp(sensors[i].pin, sensors[i].auxPin, sensors[i].index);
        if (sensors[i].actualValue >= sensors[i].alarmSP) {
           setAlarm(i);
        } else {
           sensors[i].active = false;
        }
      }
   }
   if ((activeAlarmCount == 0) and interlockTimer.started) {
      interlockTimer.started = false;
   } else if (activeAlarmCount > 1) {
      interlock(false,0);      
   }
}

#ifdef RESET_BUTTON_PIN
void checkResetButton() {
  // Check if the reset button [RESET_BUTTON_PIN] is pressed, else reset the timer. Also verifies if the reset button is pressed for a long time and inhibit it if so to avoid an auto reset when it is shortcuted.
  if (!digitalRead(RESET_BUTTON_PIN)){
    if (checkTimer(&inhibitResetTimer.startMs,RESET_INHIBIT_DELAY,&inhibitResetTimer.started)) { 
      inhibitReset = true;
      #ifdef HAS_LCD
        includeExtraMsg(0,11,false);     
      #endif 
    } else {
      startTimer(&inhibitResetTimer.startMs,&inhibitResetTimer.started);
    } 
    if (interlockStatus && !inhibitReset) {      
      #ifdef HAS_LCD
        if (!resetBtnPressed) {
          resetBtnPressed = true;
          includeExtraMsg(0,10,false);
        }
      #endif
      if (resetInterlock(true)) {
        #ifdef HAS_LCD
          includeExtraMsg(0,1,false);
        #endif      
      }
    } 
  } else {
    resetBtnPressed = false;
    resetTimer.started = false;
    inhibitReset = false;
    inhibitResetTimer.started = false;
  } 
  
}
#endif

void updateLEDs() {
  //Update Interlock and Alarm indication status led
  if (!anyAlarm) { 
    alarmLedLow();    
  }
  if (interlockStatusChanged) {
    //LED indication of interlock status
    interlockStatusChanged = false;
    #if defined(ALARM_LED_PIN) || defined(TRIP_LED_PIN) || defined(HAS_NEOPIXEL)
      updateInterlockLed(interlockStatus);
    #endif

    updateEEPROMinterlock();
    #ifdef HAS_LCD
      tripLCD = interlockStatus;
    #endif
  }  
   // Heart beat (using alarm and trip LEDs to test them)
   ledHeartBeat();
}

void setAlarm(byte index) {
  // Turn an Alarm active, start timers and light Alarm LED [ALARM_LED_PIN].
  anyAlarm = true;
  if (sensors[index].enabled) {
     activeAlarmCount++;
     if (triggerIndex == 255) {
        triggerIndex = index;
        sensors[index].trigger = true;
     }
     interlock(true,sensors[index].timer);
  }
  sensors[index].active = true;
  updateAlarmLed();
}

void startTimer(unsigned long *pStartMS, bool *timerStatus) {
   // Starts any timer
   if (!*timerStatus) {
      *pStartMS = millis();
      *timerStatus = true;
   }
}

bool checkTimer(unsigned long *pStartMS, unsigned int delayms, bool *timerStatus){
   // Checks if the timer is finished returning True on that condition
   if (!*timerStatus) {
     return false;
   } else {
      unsigned long nowMs = millis();
      if (nowMs > *pStartMS) {
          if ((nowMs - *pStartMS) > delayms) {   
            *timerStatus = false;
            return true;
        } else{
            return false;
        }
      } else {
         *pStartMS = millis();
         return false;
      }  
   }     
}

void interlock(bool useTimer, int interlockDelay) {
   // Change the output [INTERLOCK_RELAY_PIN] to an interlock position [INTERLOCK_POLARITY] after some time to prevent spurious trips
   bool interlockFlag = false;
   if (!useTimer) {
      interlockFlag = true;
   } else {
      if (checkTimer(&interlockTimer.startMs,interlockDelay,&interlockTimer.started)) { 
         if (!interlockStatus) {
            interlockFlag = true;
         }
      } else {
         startTimer(&interlockTimer.startMs,&interlockTimer.started);
      } 
   }  
   if (interlockFlag) {
       if (!minimumInterlockTimer.started) {
          startTimer(&minimumInterlockTimer.startMs,&minimumInterlockTimer.started);
       }
       interlockStatus = true;
       interlockStatusChanged = true;
       digitalWrite(INTERLOCK_RELAY_PIN,INTERLOCK_POLARITY);
       #ifdef TRIP_LED_PIN
          digitalWrite(TRIP_LED_PIN, HIGH); 
       #endif
   }   
}
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

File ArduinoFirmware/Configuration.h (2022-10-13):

/*
 ************************      Configurations module     *************************
 *
 * Copyright (c) 2021~22 Rodrigo C. C. Silva [https://github.com/SinisterRj/SafetyPrinter]
 *
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
 * You should have received a copy of the GNU General Public License
 * along with this program.  If not, see <https://www.gnu.org/licenses/>.
*/


// ****************************************************************************
// General Configurations:

// ########################  Interlock Relay  ########################
    
#define INTERLOCK_RELAY_PIN     10          // Arduino's Digital pin connected to the Printer's power supply relay.
#define INTERLOCK_POLARITY      HIGH        // Change if you need to toggle the behavior of the interlock pin (if its HIGH it means that the [INTERLOCK_RELAY_PIN] output will be LOW under normal conditions and HIGH when an interlock occurs)
#define MINIMUM_INTERLOCK_DELAY 5           // Minimum amount of time (in s) that an interlock will be active (to avoid fast switch printer on and off and possible damage it)

// ########################  Reset button  ########################

#define RESET_BUTTON_PIN        11          // Arduino's Digital pin connected to the trip reset switch (OPTIONAL).
#define RESET_DELAY             2500        // Delay for reseting the trip condition in [ms]. The user must press the reset button for this amount of time to reset a trip.
#define RESET_INHIBIT_DELAY    20000        // Delay for inhibiting reset button to avoid an auto reset if it is shortcuted.

// ########################  Auto-Reset  ########################

#define ARDUINO_RESET_PIN       2           // Arduino's Digital pin connected to RST pin (resets Arduino via serial C9 command to allow firware update from octoprint's plugin).

// ########################  Alarm & trip LED indication  ########################

#define HAS_NEOPIXEL                        // Use a neopixel led or strip to indicate the Safety Printer MCU status (OPTIONAL).
#ifdef HAS_NEOPIXEL
  #define NEOPIXEL_PIN          13          // Arduino's Digital pin connected to the neopixels strip data line.
  #define NEOPIXEL_COUNT        1           // Number of neopixels (LEDs) on the strip.
  #define NEOPIXEL_TYPE         NEO_GRB     // Neopixel color order: NEO_RGB, NEO_GRB or NEO_RGBW.
  #define NEOPIXEL_BRIGHTNESS   125         // Neopixel leds brightness. Any value from 0 to 255.
  #define NORMAL_RGB            60,255,10   // Normal status neopixel color in [Red,Green,Blue,White].
  #define ALARM_RGB             255,255,0   // Alarm status neopixel color in [Red,Green,Blue,White].
  #define TRIP_RGB              255,0,0     // Trip status neopixel color in [Red,Green,Blue,White].
  #define ALARM_BLINK           500         // Alarm color blink interval in [ms]       
#else
  #define ALARM_LED_PIN           13        // Arduino's Digital pin connected to the alarm indication LED (OPTIONAL).
  #define TRIP_LED_PIN            12        // Arduino's Digital pin connected to the trip indication LED (OPTIONAL).
  #define LED_DELAY               5000      // Led heart beat interval in [ms]
#endif

// ########################  Serial Communication  ########################

#define HAS_SERIAL_COMM                     // Uncomment to Enable serial communications. Needed to interface with Octoprint plugin (OPTIONAL)
#ifdef HAS_SERIAL_COMM
  #define BAUD_RATE             38400       // :[2400, 9600, 19200, 38400, 57600, 115200]
#endif

// ########################  LCD  ########################

#define HAS_LCD                             // Uncomment to Enable the use of a 2x16 I2C LCD. (OPTIONAL)    
#ifdef HAS_LCD
  #define LCD_DELAY             2000        // LCD refresh rate in ms
  #define LCD_ADDRESS           0x27        // LCD I2C address
  #define LCD_SDA_PIN           A4          // I2C data PIN (always use A4 for Arduino Uno or Nano)
  #define LCD_SCL_PIN           A5          // I2C clock PIN (always use A5 for Arduino Uno or Nano)      
#endif

// ########################  Sensors  ########################

/* 

Sensor configuration:

Max: 8 sensors

All sensors have the same structure:
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

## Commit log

2021-04-07 Changed folder name to - ArduinoFirmware
2021-04-07 Create Safety Printer.fzz
    [Safety Printer.fzz]
2021-04-27 Octoprint Plugin release
    [babel.cfg]
2021-04-27 No connection UI correction
    [babel.cfg]
2021-05-26 reorganização
    [babel.cfg]
2021-05-26 ver 0.2.1
    1) Include analog type of sensor to allow Hotend temperature measurement.
    2) included command <c5> to save on EEPROM sensors Enabled status and alarm set points
    3) 2 new serial commands: Remote shutdown and enable/disable sensors
    4) Now it indicates Alarm even if the sensor is disabled (but not starts de trip)
    5) Included command <r4> to return firmware version and release date
2021-05-27 General clean-up
    Solved Bug: now only send commands to arduino if user changes the set point on settings;
    Terminal Improvement: Copy more functions from octoprint terminal to focus on command line and just scrolls when tab has focus.
2021-05-28 Auto serial port improvement
    Plugin don't connect if the default serial port is AUTO and the printer is not connected to avoid it to connect to the printer instead of the safety printer MCU. Also the default serial port combo box is now updated when user clicks on it.
2021-05-28 Include: Hot End NTC Sensor
    [Safety Printer.fzz]
2021-05-29 Add Terminal filter
    extra: Remove "termios" library from connection.py
2021-06-01 Shutdown after finish printing.
2021-06-01 Include C6 command for turn on/off printer
    Comands arguments now are case insensitive.
2021-07-29 Version 0.2.3
    Firmware:
    1) Fix a bug when reading EEPROM data.
    2) Split project into multiple files.
    3) Checks EEPROM for CRC.
    4) Update <c4> command to send EEPROM and Serial Protocol versions
    Plugin:
    1) Create a terminal TAB,
    2) Checks for firmware communication version instead of firmware version,
    3) Create an individual plugin LOG file,
    4) Minor visual enhacements.
    [EEPROM.ino, SafetyPrinter.ino, Serial.ino]
2021-07-30 0.2.4
    1) Include Marlin Thermistor files for better thermistor configuration;
    2) Configuration.h created.
    [Configuration.h]
2021-08-01 Include Bed Temp. NTC sensor
    [Safety Printer.fzz]
2021-08-05 Better connection and error notifications
    1) Improves printer comm. port identification and dealing. Now don't show printer port on plugin settings.
    2) Implements pop up notifications for all error messages.
    3) Logging all levels.
2021-08-30 Moved Octoprint Plugin
    Moved Octoprint Plugin to specific repo: https://github.com/SinisterRj/Octoprint_SafetyPrinter
    [babel.cfg]
2021-09-10 Version 0.2.5
    1) Include CRC check on <r1>,<r2> and <r4> responses;
    2) Organize some thermisotr tables and Configuration.h file;
    3) Check for some errors on sensor configuration and disable it.
    4) Include commands alias;
    5) Include free memory, voltage, temperature and cycle time monitoring;
    [Configuration.h]
2021-10-21 0.2.5b
    6) Include I2C 16x2 LCD support
    7) Creates "lowSP" and "highSP" sensor values (now user can choose different sensors);
    8) <R2> now sends "forceEnable", "lowSP" and "highSP" values;
    9) Include a timer to avoid sucessive trips/resets or turns on/off on printer and damage it.
    [Configuration.h]
2021-10-21 0.2.5b
    Include LCD
    [Safety Printer.fzz]
2021-10-22 0.2.5c
    Check for compiling without optionals.
    [Configuration.h]
2021-10-27 Fix LCD GND and VCC conections
    Fix LCD GND and VCC conections;
    Include MT3608 module name to buck converter.
    [Safety Printer.fzz]
2022-03-11 1.1.1rc1
    1.1.1rc1
    [Configuration.h, SafePrinterBoard_0_5.brd, SafePrinterBoard_0_5.sch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]
2022-03-11 Revert "0.2.6a"
    [Configuration.h, SafePrinterBoard_0_5.brd, SafePrinterBoard_0_5.sch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]
2022-08-30 0.2.6rc1
    30/08/22
    Changes:
    1) New default pin out to match with the official Safety Printer Arduino Shield;
    2) Include <R6> command to repeat intro msg;
    3) Remove "booting..." string from the setup;
    4) Auto detects different Arduino boards;
    5) Include command <r7> to report Printer's power status (user request) - Integration with PSU Control;
    6) Include command <c9> to reset the Safety Printer MCU. This command allows firmware update.
    7) Command <R4> returns board Type;
    8) Include ARDUINO_RESET_PIN;
    9) Include neopixels as status indicator;
    10) Fix a bug that makes wrong temperature readings if your declared sensor that don't match with the sensor's count.
    [Configuration.h, Safety Printer.fzz]
2022-08-30 Board Ver 0.6
    1) Adds capacitor to avoid autoreset upon serial connection;
    2) Removes UART connector;
    3) Adds neopixel support for alarm and trip LEDs;
    4) Removes some unused holes;
    5) Rearranges some connectors to avoid Arduino UNO USB connector short circuit.
    [SafePrinterBoard_0_5.sch, SafePrinterBoard_0_6.brd, SafePrinterBoard_0_6.sch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]
2022-09-26 Add notes to schematics
2022-09-27 Fix Neopixel pin
    [Configuration.h]
2022-10-13 0.2.7
    1) Monitors RESET button to a continuous operation (shortcircuited) and disables it to avoid auto reset after a trip.
    [Configuration.h]

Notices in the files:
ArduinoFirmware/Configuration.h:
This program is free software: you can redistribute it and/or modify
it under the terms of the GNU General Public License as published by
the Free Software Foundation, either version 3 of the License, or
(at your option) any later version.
